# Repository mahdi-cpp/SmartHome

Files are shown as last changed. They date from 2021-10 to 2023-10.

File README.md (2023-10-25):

## Smart Home Automation Project
This Project is designed in 2014 and assembled on more than 200 home in iran

## STM32F103RBT6
The STM32F103xx medium-density performance line family incorporates the high-
performance ARM ® Cortex ® -M3 32-bit RISC core operating at a 72 MHz frequency, high-
speed embedded memories (Flash memory up to 128 Kbytes and SRAM up to 20 Kbytes),
and an extensive range of enhanced I/Os and peripherals connected to two APB buses. All
devices offer two 12-bit ADCs, as well as standard and advanced communication interfaces: up to two I 2 Cs and SPIs, three USARTs, an USB and a CAN.

* PLC (Programmable logic controller) Serial Port Connection
* FAT File System read sound voices 
* Connect To MT8888C Process 
* Connect to VS1003 Via SPI Protocol for Play Voices
* Debugger Serial Port

## ATmega8A-AU
The ATmega8 is a low-power CMOS 8-bit microcontroller based on the AVR RISC architecture.
By executing powerful instructions in a single clock cycle, the ATmega8 achieves throughputs
approaching 1 MIPS per MHz, allowing the system designer to optimize power consumption ver-
sus processing speed.

- Connect to PT2264 remote control encoder and receive commands

## SIM900
SIMCom presents an ultra compact and reliable wireless module-SIM900. This is a complete Quad-band GSM/GPRS module in a SMT type and designed with a very powerful single-chip processor integrating AMR926EJ-S core, allowing you to benefit from small dimensions and cost-effective solutions.

- Send sms notifications to users
- Send sms alarm security to users
- Receive Command of user

## MT8888CS
Integrated DTMF Transceiver with Intel Micro Interface 

- Call users and play alarm security sounds
- Receive user commands

## VS1003
- MP3/WMA AUDIO CODEC: Ring to phone and play mp3 file for user, for example ring and play security sound

## MAX232DR
- Conectin Between STM32F103 <---> PLC
- Conectin Between STM32F103 <---> SIM900
- Conectin Between STM32F103 <---> Debuger

## PT2264
PT2264 is a remote control encoder paired with PT2294 utilizing CMOS Technology. It encodes data
and address pins into a serial coded waveform suitable for RF modulation. PT2264 has a maximum of
12-bit of tri-state address pins providing up to 531,441 (or 312) address codes; thereby, drastically
reducing any code collision and unauthorized code scanning possibilities. 

- 12 Chanel input remote control. for example of usage: lighting control, open door, music ...

<div align="center">
  <a href="https://github.com/othneildrew/Best-README-Template">
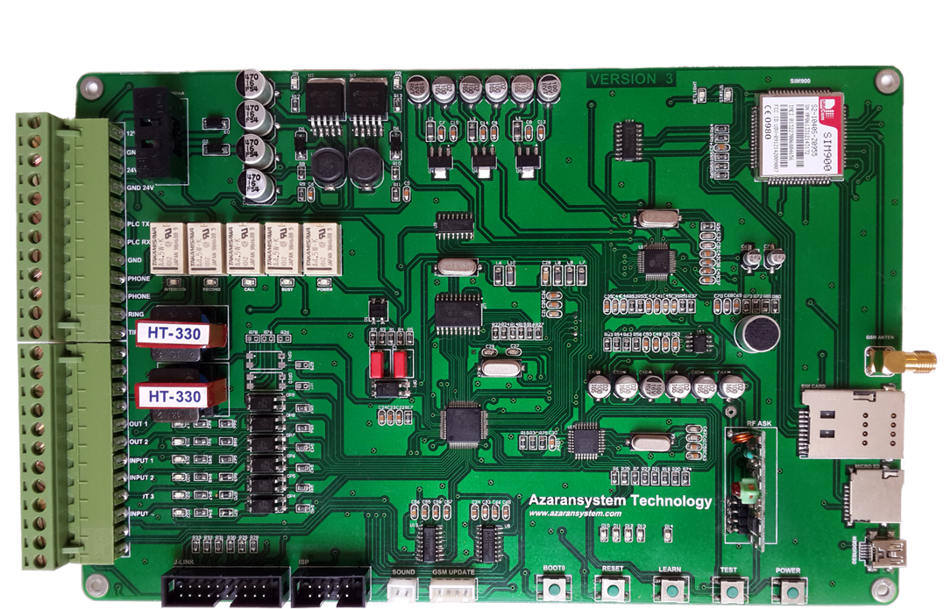
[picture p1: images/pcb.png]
    
  </a>
</div>

<div align="center">
  <a href="https://github.com/othneildrew/Best-README-Template">
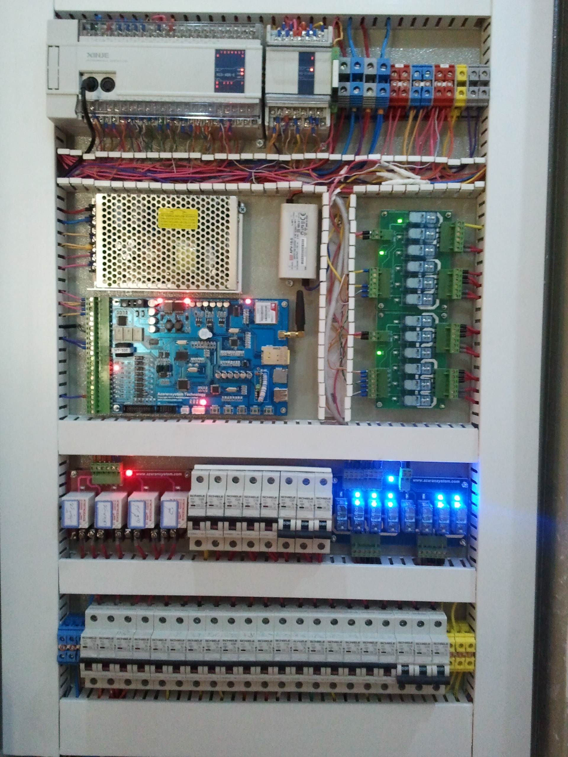
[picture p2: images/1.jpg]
    
  </a>
</div>

<div align="center">
  <a href="https://github.com/othneildrew/Best-README-Template">
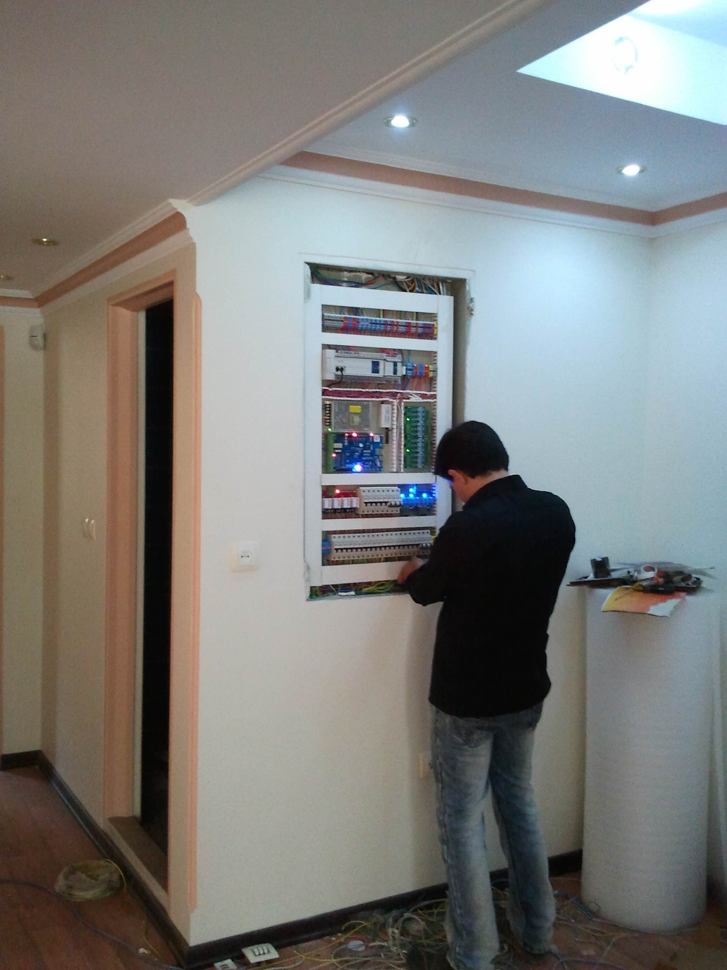
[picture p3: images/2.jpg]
    
  </a>
</div>

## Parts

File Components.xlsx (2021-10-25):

Comment | Designator | Footprint | Quantity
100nF / 100V | C1, C2 | RAD-0.3 | 2
470UF / 16V | C3, C4, C19, C20 | 470UF-SMD | 4
100nF | C5, C6, C7, C8, C9, C13, C14, C15, C22, C23, C24, C25, C26, C30, C33, C34, C35, C37, C38, C40, C41, C42, C43, C49, C50, C51, C52, C54, C55, C56, C57, C58, C59, C63, C65, C66, C69, C70 | 0805C | 38
100uF / 16V SMD | C10, C11, C12, C16, C17, C18, C36, C47, C48, C53, C60, C64 | 100UF-SMD | 12
10nF | C21, C39, C44, C45, C46 | 0805c | 5
15PF | C27, C29, C61, C62, C73, C75, C77 | 0805c | 7
100uF / 100V | C28 | 1206 | 1
33P | C31, C32, C72, C74, C76 | 0805c | 5
10uF | C67, C71 | 10UF-SMD | 2
100pF | C68 | 0805C | 1
ISP | CN1 | IDC2.54-V10D | 1
HD08-T | D1 | HD08-T | 1
Diode 1N4007 | D2, D3 | Diode | 2
LED | D4, D7, D8, D9, D10, D11, D12, D13, D14, D15, D16, D17, D18, D19, D20, D21, D22, D23, NETLIGHT, STATUS | 0805d | 20
1N5822 | D5, D6 | SMB | 2
FUSE 3A | F1 | FUSE | 1
IDC 20 | J-LINK | IDC2.54-V20D | 1
RELAY 5V | K1, K2, K3, K4, K5 | RELAY G6H | 5
FREAT | L1, L2, L3, L6, L7, L8, L9, L10 | 1206 | 8
100UH | L4, L5 | 100UH 1 | 2
sim900 | M1 | sim900 | 1
CON 2PIN | MIC | Microphone | 2
EL817 | OP1, OP4, OP5, OP6, OP7, OP8, OP9, OP10, OP11 | EL817 | 9
FONIX-12 | P1, P2 | Fonit_Conector | 2
Mini USB | P3 | miniusb | 1
RF ASK | P4 | ASK-RF | 1
CON 4 | P5 | CON_4PIN | 1
GSM ANTEN | P6 | anten-jack | 1
CON 2PIN | P7 | CON_2PIN | 1
2.2K | R1 | 0805 | 1
100K | R2, R16, R27, R58 | 0805 | 4
330R | R3, R4 | 0805 | 2
10K | R5, R6, R7, R9, R11, R14, R17, R19, R28, R29, R30, R31, R32, R33, R40, R41, R42, R43, R46, R47, R48, R49, R61, R62, R76 | 0805 | 25
4.7K | R8, R75, R77, R79 | 0805 | 4
3.3K | R10, R24, R35 | 0805 | 3
1K | R12, R13, R18, R20, R21, R22, R25, R34, R38, R39, R44, R45, R53, R56, R57, R64, R65, R66, R67, R68, R69, R70, R71, R72, R73, R74, R80, R81 | 0805 | 28
4.7M | R15 | 0805 | 1
330K | R23 | 0805 | 1
47K | R26 | 0805 | 1
1M | R36 | 0805 | 1
470R | R37 | 0805 | 1
22R | R50, R51, R52, R55, R59, R60 | 0805 | 6
100R | R54, R63 | 0805 | 2
220 | R78 | 0805 | 1
MICRO SD | S1 | MicroSD | 1
SIM CARD SOKET | SIM1 | SIM HOLDER 2 | 1
SWITCH | SW1, SW2, SW3, SW4, SW5 | SWICH | 5
TRANCE 300 :300 | T1, T2 | trance | 2
STM32F103RBT6 | U1 | LQFP64_L | 1
LM2576S-ADJ | U2, U3 | TS5B_N | 2
AMS1117-2.5V | U4 | sot223 | 1
AMS1117-3.3V | U5 | sot223 | 1
AMS1117-2.8V | U6 | sot223 | 1
MT8888CS | U7 | SOIC20_N | 1
MAX232DR | U8, U13 | L16_N | 2
ULN2003L | U9, U14 | L16_N | 2
VS1003 | U10 | 48A | 1
LM386M | U11 | M08A_N | 1
ATmega8A-AU | U15 | 32A_N | 1
3.579545 MHz | X1 | crystal | 1
8MHz | X2 | crystal | 1
12.288MHz | X4 | crystal | 1
16MHz | X5 | crystal | 1

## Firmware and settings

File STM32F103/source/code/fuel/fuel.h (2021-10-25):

#ifndef _FUEL_H
  #define _FUEL_H

  //#include <ctype.h>
  //#include <errno.h>
  //#include <math.h>
  #include <stdio.h>
  #include <stdlib.h>
  #include <string.h>
  #include "ff.h"
  //#include <time.h>
  //#include <wchar.h>
  //#include <wctype.h>



  /* Default configuration filename. */
  #define DEFAULT_CONFIG_FILE "system.txt"
  #define DEFAULT_SD_CONFIG_FILE "1:/machine/machine1/sd.txt"


  #define BUF_SIZ 150
  #define LINE 19
  #define NUM 1
  #define PWD_LEN 6
  #define TRUE 1
  #define FALSE 0
  #define OK  0
  #define ERR  -1
  #define VERSION "1.0.1"

  /*SD卡配置文件action，决定此次配置的动作*/
  enum action
  {
    W_CONFIG = 0,  /*更新配置文件*/
    R_CONFIG,  /*读取配置文件*/
    COPY_TO_SD,  /*拷贝数据到SD卡*/
  };

  /*油箱的形状*/
  enum shape_t
  {
    CYLINDER = 0, CUBE,
  };

  typedef struct cuber_s
  {
    unsigned short height;
    unsigned short length;
    unsigned short width;
  } cube_t;

  typedef struct cylinder_s
  {
    unsigned short len;
    unsigned short radius;
  } cylinder_t;

  union parameter
  {
    cube_t cube;
    cylinder_t cylinder;
  };


  typedef struct config_s
  {
    char name[LINE + 1];
    char pwd[PWD_LEN];
    unsigned short shape;
    unsigned int capacity;
    union parameter u;
  }
  config_t;

  extern config_t g_data;
  extern int load_config(void);
  extern int load_config_from_sd(int *action);
  extern void write_file_tmp(void);

#endif

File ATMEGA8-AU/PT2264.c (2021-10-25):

/*
    This version is compatible PCB Board of VERSION 3 
*/


#include <mega8.h>
#include <stdio.h>
#include <delay.h>

#define      LED_ON            PORTD.7 = 1
#define      LED_OFF           PORTD.7 = 0

#define      BUZZER_ON         PORTC.0 = 1
#define      BUZZER_OFF        PORTC.0 = 0

#define      LEARN             PIND.0

#define      YES               1
#define      NO                0

#define      OK                1

#define      BIT0              0
#define      BIT1              1
#define      FLOATING          2





#define     LED1            PORTD.7
#define     LED2            PORTD.6
#define     LED3            PORTD.5
#define     LED4            PORTD.4

#define     POWER_LED       PORTC.5





#define     RELAY_OUT       PORTB.0 
#define     RELAY_SELECT    PORTB.1
#define     RELAY_POWER     PORTB.2

#define     M8_TO_STM32     PORTC.4


#define     M8_Q0           PORTC.0 
#define     M8_Q1           PORTC.1
#define     M8_Q2           PORTC.2  
#define     M8_Q3           PORTC.3

#define     STM32_Q0        PINC.0 
#define     STM32_Q1        PINC.1 
#define     STM32_Q2        PINC.2 
#define     STM32_Q3        PINC.3 

#define     DELAY           120 

#define     SET_OUTPUT      DDRC = 0x3F 
#define     SET_INPUT       
  
    

short int PowerStatus = 0 , STM32Data, POWER_LED_Cunter, KEY_PRESS = 0;

//char string[20];
int StartPower = 0;

float T1, T2, DutyCycle;

bit RisingEdge = OK, StartT2 = NO, GetPulse = NO, Sync = NO, AddressReceive = NO;

short int i = 0, j = 0, PulseNumber = 1, Pulse1, Pulse2;

short int  AddressData1[12];
short int  AddressData2[12];
short int  AddressData[8];
eeprom short int  EepromAddressData[8];

short int NumberPacket = 1, Error = NO;
//short int receive = 0, 
short int  Data;

void Init(){




PORTB=0x00;
DDRB=0x07;


PORTC=0x00;
DDRC=0x30;


PORTD=0x03;
DDRD=0xF0;



// Timer/Counter 1 initialization
// Clock source: System Clock
// Clock value: 2000.000 kHz
// Mode: Normal top=0xFFFF
// OC1A output: Discon.
// OC1B output: Discon.
// Noise Canceler: Off
// Input Capture on Falling Edge
// Timer1 Overflow Interrupt: Off
// Input Capture Interrupt: Off
// Compare A Match Interrupt: Off
// Compare B Match Interrupt: Off
TCCR1A=0x00;
TCCR1B=0x02;
TCNT1H=0x00;
TCNT1L=0x00;
ICR1H=0x00;
ICR1L=0x00;
OCR1AH=0x00;
OCR1AL=0x00;
OCR1BH=0x00;
OCR1BL=0x00;


  

// External Interrupt(s) initialization
// INT0: On
// INT0 Mode: Rising Edge
// INT1: On
// INT1 Mode: Rising Edge
GICR|=0xC0;
MCUCR=0x0F;
GIFR=0xC0;


    // Global enable interrupts
    #asm("sei")
    

    
    for(i=0; i<8; i++)
       AddressData[i]= EepromAddressData[i];
}



// External Interrupt 0 service routine
interrupt [EXT_INT0] void ext_int0_isr(void)
{
    if(PowerStatus == 1)
    {
        SET_INPUT;
        delay_ms(2);
        STM32Data =  (STM32_Q0 == 1) ? 1 : 0;
		STM32Data += (STM32_Q1 == 1) ? 2 : 0;
		STM32Data += (STM32_Q2 == 1) ? 4 : 0;
		STM32Data += (STM32_Q3 == 1) ? 8 : 0; 
        
        if(STM32Data == 7)
        {
            LED1 = 1;
            LED2 = 1;
            LED3 = 1;
            LED4 = 1; 
            delay_ms(1000);
            LED1 = 0;
            LED2 = 0;
            LED3 = 0;
            LED4 = 0;
        }
    }
        
}

// External Interrupt 1 service routine
interrupt [EXT_INT1] void ext_int1_isr(void)
{
    
    if(RisingEdge == YES)   //Rising Edge
    {  
     
        if(StartT2 == YES)
        {
            T2 = TCNT1;
            StartT2 = NO;
            GetPulse = OK;
        }
        TCNT1 = 0;
        //MCUCR=0x08;     //INT1 Mode : Falling Edge
        RisingEdge = NO; 
        
        // External Interrupt(s) initialization
        // INT0: On
        // INT0 Mode: Rising Edge
        // INT1: On
        // INT1 Mode: Falling Edge
        
        MCUCR=0x0B;
        
    }
    else    // Falling Edge
    {  
        T1 = TCNT1;
        TCNT1 = 0;

        // External Interrupt(s) initialization
        // INT0: On
        // INT0 Mode: Rising Edge
        // INT1: On
        // INT1 Mode: Rising Edge
        
        MCUCR=0x0F;
        
        
        RisingEdge = OK;
        StartT2 = OK;
    }

    if( GetPulse == OK) {
         
        if(Sync == NO)
        {  
            DutyCycle = (T1 / (T1 + T2));
            if(DutyCycle > 0.015 && DutyCycle < 0.035) //Normal 0.0333
            {   
                Sync = OK;
                AddressReceive = YES; 
                Error = NO;
                PulseNumber = 1;
                i = 0;
                j = 0;
            }
        }
        else if(AddressReceive == YES)
        {
            DutyCycle = (T1 / (T1 + T2));

            if(i != 16)
            {
                if(DutyCycle > 0.15 && DutyCycle < 0.3) //4a  Normal 0.239
                {
                    if(PulseNumber == 1)
                        Pulse1 = 4;
                    else if(PulseNumber == 2)
                        Pulse2 = 4; 
                }
                else if(DutyCycle > 0.5 && DutyCycle < 0.8) //12a  Normal 0.729
                {
                    if(PulseNumber == 1)
                        Pulse1 = 12;
                    else if(PulseNumber == 2)
                        Pulse2 = 12; 
                }
                else
                {
                    for(i=0; i<12; i++)
                    {
                        AddressData1[i] = 0;
                        AddressData2[i] = 0;                        
                    }
                        
                    NumberPacket = 1; 
                    Error = NO;   
                    AddressReceive = NO;
                    PulseNumber = 1;
                    Sync = NO;
                    i = 0;
                    j = 0;
                    TCNT1 = 0; 
                    RisingEdge = OK;
                    // External Interrupt(s) initialization
                    // INT0: On
                    // INT0 Mode: Rising Edge
                    // INT1: On
                    // INT1 Mode: Falling Edge
                    
                    MCUCR=0x0B;
                  
                    
                    StartT2 = NO;
                    GetPulse = NO;
                    goto EndInterrupt;
                }

                if(PulseNumber == 2)
                {
                    if( Pulse1 == 4 && Pulse2 == 4)
                    {
                        if(NumberPacket == 1)
                            AddressData1[j] = BIT0 ; 
                        else if(NumberPacket == 2)
                            AddressData2[j] = BIT0 ;
                    }    
                    else if(Pulse1 == 12 && Pulse2 == 4)
                    {
                        if(NumberPacket == 1)
                            AddressData1[j] = BIT1 ; 
                        else if(NumberPacket == 2)
                            AddressData2[j] = BIT1 ;
                    }                        
                    else if(Pulse1 == 4 && Pulse2 == 12)
                    {  
                        if(NumberPacket == 1)
                            AddressData1[j] = FLOATING ; 
                        else if(NumberPacket == 2)
                            AddressData2[j] = FLOATING ;
                    }
                    j++;
                }
                                                               
                
                if(PulseNumber == 1) 
                    PulseNumber = 2;
                else if(PulseNumber == 2)
                    PulseNumber = 1;
            }

            i++;
            
            if(i > 23)
            {
                
                if(NumberPacket == 2)
                {   
                    for(i=0; i<12; i++)
                        if(AddressData1[i] != AddressData2[i])
                            Error = YES;
                    
                    if(Error == NO)
                    {   
                        if(!LEARN)
                        {
                            for(i=0; i<4; i++)
                            {   
                                LED1 = 1;
                                LED2 = 1;
                                LED3 = 1;
                                LED4 = 1;
                                delay_ms(100);
                                LED1 = 0;
                                LED2 = 0;
                                LED3 = 0;
                                LED4 = 0;  
                                delay_ms(100);
                                //BUZZER_ON;
                                //delay_ms(50);
                                //BUZZER_OFF;
                                //delay_ms(50);  
                            }
                            
                            for(i=0; i<8; i++)
                            {
                                EepromAddressData[i] = AddressData1[i]; 
                                AddressData[i] = AddressData2[i]; 
                                //lcd_clear();
                                //sprintf(string, "%0d %0d %0d %0d %0d %0d %0d %0d", AddressData[0] , AddressData[1], AddressData[2], AddressData[3], AddressData[4], AddressData[5], AddressData[6], AddressData[7]);
                                //lcd_gotoxy(0, 0);
                                //lcd_puts(string);
                            }    
                        }
                        else
                        {  
                            Error = NO;
                            
                            for(i=0; i<8; i++)
                            {
                                if(AddressData[i] != AddressData2[i])
                                {
                                    Error = YES;  
                                    
                                    //lcd_clear();   
                                    //sprintf(string, "%0d %0d %0d %0d %0d %0d %0d %0d", AddressData2[0] , AddressData2[1], AddressData2[2], AddressData2[3], AddressData2[4], AddressData2[5], AddressData2[6], AddressData2[7]);
                                    //lcd_gotoxy(0, 0);
                                    //lcd_puts(string);
                                    //sprintf(string, "NO MATCH ADDRESS");
                                    //lcd_gotoxy(0, 1);
                                    //lcd_puts(string);  

                                    LED1 = 1;
                                    LED2 = 1;
                                    LED3 = 1;
                                    LED4 = 1;
                                    delay_ms(200);
                                    LED1 = 0;
                                    LED2 = 0;
                                    LED3 = 0;
                                    LED4 = 0;

                                } 
                            }
                                    
                            if(Error == NO)
                            {
                                
                                //lcd_clear();
                                //sprintf(string, "%0d %0d %0d %0d %0d %0d %0d %0d", AddressData1[0] , AddressData1[1], AddressData1[2], AddressData1[3], AddressData1[4], AddressData1[5], AddressData1[6], AddressData1[7]);
                                //lcd_gotoxy(0, 0);
                                //lcd_puts(string);

                                Data = ((AddressData1[8]*1000) + (AddressData1[9]*100) + (AddressData1[10]*10) + AddressData1[11]);
                                LED1 = 0;
                                LED2 = 0;
                                LED3 = 0;
                                LED4 = 0;
                                switch(Data){
                                    case 20:      //0001 
                                        Data = 1;
                                        LED4 = 1; 
                                        break; 
                                    case 210:     //0010   
                                        Data = 2;
                                        LED3 = 1; 
                                        break;
                                    case 200:     //0011 
                                        Data = 3;
                                        LED3 = 1;  
                                        LED4 = 1;
                                        break; 
                                    case 2100:    //0100 
                                        Data = 4;
                                        LED2 = 1;  
                                        break; 
                                    case 2120:    //0101    
                                        LED2 = 1;
                                        LED4 = 1;
                                        Data = 5;
                                        break;
                                    case 2010:    //0110 
                                        LED2 = 1;
                                        LED3 = 1;
                                        Data = 6;
                                        break;
                                    case 2000:   //0111  
                                        LED2 = 1;
                                        LED3 = 1;
                                        LED4 = 1;
                                        Data = 7;
                                        break; 
                                    case 1000:   //1000
                                        LED1 = 1;
                                        Data = 8;
                                        break;
                                    case 1020:   //1001
                                        LED1 = 1;
                                        LED4 = 1;
                                        Data = 9;
                                        break; 
                                    case 1210:   //1010  
                                        LED1 = 1;
                                        LED3 = 1;
                                        Data = 10; 
                                        break; 
                                    case 1200: //1011
                                        LED1 = 1;
                                        LED3 = 1;
                                        LED4 = 1;
                                        Data = 11;
                                        break;
                                    case 100: // 1100
                                        LED1 = 1;
                                        LED2 = 1;
                                        Data = 12;
                                        break;
                                }
                                
                                SET_OUTPUT;
                                M8_Q0 = LED4; 
                                M8_Q1 = LED3;
                                M8_Q2 = LED2;
                                M8_Q3 = LED1; 
                                
                                delay_ms(2);
                                
                                M8_TO_STM32 = 1;
                                delay_ms(8);
                                M8_TO_STM32 = 0; 
                                delay_ms(8);
                                M8_Q0 = 0;
                                M8_Q1 = 0;
                                M8_Q2 = 0;
                                M8_Q3 = 0;
                                SET_INPUT;
                                
                                //sprintf(string, "%0d", Data);
                                //lcd_gotoxy(0, 1);
                                //lcd_puts(string);
                                //receive = 1; 
                            }
                        }
                        
                    }  
                    for(i=0; i<12; i++)
                    {
                        AddressData1[i] = 0; 
                        AddressData2[i] = 0;
                    }
                    NumberPacket = 1;     
                } 
                else
                { 
                    NumberPacket = 2;
                }
                
                Error = NO;
                AddressReceive = NO;
                PulseNumber = 1;
                Sync = NO;
                i = 0;
                j = 0;
                TCNT1 = 0;
                RisingEdge = OK;

                // External Interrupt(s) initialization
                // INT0: On
                // INT0 Mode: Rising Edge
                // INT1: On
                // INT1 Mode: Falling Edge
               
                MCUCR=0x0B;
                
                    
                RisingEdge = OK;
                StartT2 = NO;
                GetPulse = NO;
                goto EndInterrupt;
            }
        }

        GetPulse = NO;
    }
    EndInterrupt: 
 
    //Add to version 2     
    POWER_LED_Cunter++;
    if(POWER_LED_Cunter > 5000 && PowerStatus == 1)
    {
        POWER_LED = 1 ;
    }
    if(POWER_LED_Cunter > 5500 && PowerStatus == 1)
    {
        POWER_LED = 0 ;
        POWER_LED_Cunter = 0; 
    } 
}
//-----------------------------------------------------------------------------------



void main(void)
{
    POWER_LED = 0;
    Init();

      while (1)
      {
           /* 
            if(!LEARN){
                M8_TO_STM32 = 1;
                delay_ms(250);
                M8_TO_STM32 = 0;
            }
           */
            if(StartPower == 0)
            {   
                POWER_LED = 0;
                delay_ms(4000); 
                LED1 = 1;
                delay_ms(DELAY);                
                LED1 = 0; 
                LED2 = 1;
                delay_ms(DELAY);                 
                LED2 = 0; 
                LED3 = 1;
                delay_ms(DELAY);                  
                LED3 = 0; 
                LED4 = 1;
                delay_ms(DELAY);   
                LED4 = 0; 
                
                
                //RELAY_OUT = 1;
                RELAY_POWER = 1;
                
                PowerStatus = 1;
                delay_ms(20);
                
                StartPower = 1;
            }
             
            
            if(PIND.1 == 1) 
                KEY_PRESS = 0;
                
            if(PIND.1 == 0 && PowerStatus == 0 && KEY_PRESS == 0)
            {  
                KEY_PRESS = 1;
                
                LED1 = 1;
                delay_ms(DELAY);                
                LED1 = 0; 
                LED2 = 1;
                delay_ms(DELAY);                 
                LED2 = 0; 
                LED3 = 1;
                delay_ms(DELAY);                  
                LED3 = 0; 
                LED4 = 1;
                delay_ms(DELAY);   
                LED4 = 0; 
                POWER_LED = 0;
                
                //RELAY_OUT = 1;
                RELAY_POWER = 1;
                
                PowerStatus = 1;
                delay_ms(20);
            }
            else if(PIND.1 == 0 && PowerStatus == 1 && KEY_PRESS == 0) //if Device On
            {    
                KEY_PRESS = 1;
                
                PowerStatus = 0;
                POWER_LED = 0;    
                LED4 = 1;
                delay_ms(DELAY);                
                LED4 = 0; 
                LED3 = 1;
                delay_ms(DELAY);                 
                LED3 = 0; 
                LED2 = 1;
                delay_ms(DELAY);                  
                LED2 = 0; 
                LED1 = 1;
                delay_ms(DELAY);   
                LED1 = 0; 
                
                //RELAY_OUT = 0;
                RELAY_POWER = 0; 
                                
                delay_ms(20);
            } 
            
            
 }                 
}

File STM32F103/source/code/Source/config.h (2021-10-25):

#ifndef __Config_h
#define __Config_h

//#include "stm32f10x.h"
#include "stm32f10x_lib.h"
#include "stm32f10x_type.h"
#include "integer.h"
#include "delay.h"
#include <stdio.h>
#include <string.h>
#include <stdlib.h>
#include <math.h>
#include "ff.h"
#include "RTC_Time.h"
#include "stm32f10x_rcc.h"
#include "fuel.h"
#include "Serial.h"
#include "SerialProcess.h"
#include "shell.h"
#include "FATFS_cmds.h"
#include "stm32f10x_exti.h"


#define BITBAND(addr, bitnum) ((addr & 0xF0000000)+0x2000000+((addr &0xFFFFF)<<5)+(bitnum<<2)) 
#define MEM_ADDR(addr)  *((volatile unsigned long  *)(addr)) 
#define BIT_ADDR(addr, bitnum)   MEM_ADDR(BITBAND(addr, bitnum)) 

#define GPIOA_ODR_Addr    (GPIOA_BASE+12) //0x4001080C 
#define GPIOB_ODR_Addr    (GPIOB_BASE+12) //0x40010C0C 
#define GPIOC_ODR_Addr    (GPIOC_BASE+12) //0x4001100C 
#define GPIOD_ODR_Addr    (GPIOD_BASE+12) //0x4001140C 
#define GPIOE_ODR_Addr    (GPIOE_BASE+12) //0x4001180C 
#define GPIOF_ODR_Addr    (GPIOF_BASE+12) //0x40011A0C    
#define GPIOG_ODR_Addr    (GPIOG_BASE+12) //0x40011E0C    

#define GPIOA_IDR_Addr    (GPIOA_BASE+8) //0x40010808 
#define GPIOB_IDR_Addr    (GPIOB_BASE+8) //0x40010C08 
#define GPIOC_IDR_Addr    (GPIOC_BASE+8) //0x40011008 
#define GPIOD_IDR_Addr    (GPIOD_BASE+8) //0x40011408 
#define GPIOE_IDR_Addr    (GPIOE_BASE+8) //0x40011808 
#define GPIOF_IDR_Addr    (GPIOF_BASE+8) //0x40011A08 
#define GPIOG_IDR_Addr    (GPIOG_BASE+8) //0x40011E08 
 

#define PAout(n)   BIT_ADDR(GPIOA_ODR_Addr,n) 
#define PAin(n)    BIT_ADDR(GPIOA_IDR_Addr,n) 

#define PBout(n)   BIT_ADDR(GPIOB_ODR_Addr,n)  
#define PBin(n)    BIT_ADDR(GPIOB_IDR_Addr,n) 

#define PCout(n)   BIT_ADDR(GPIOC_ODR_Addr,n) 
#define PCin(n)    BIT_ADDR(GPIOC_IDR_Addr,n)  

#define PDout(n)   BIT_ADDR(GPIOD_ODR_Addr,n)  
#define PDin(n)    BIT_ADDR(GPIOD_IDR_Addr,n) 

#define PEout(n)   BIT_ADDR(GPIOE_ODR_Addr,n)  
#define PEin(n)    BIT_ADDR(GPIOE_IDR_Addr,n)  

#define PFout(n)   BIT_ADDR(GPIOF_ODR_Addr,n)  
#define PFin(n)    BIT_ADDR(GPIOF_IDR_Addr,n)  

#define PGout(n)   BIT_ADDR(GPIOG_ODR_Addr,n)  
#define PGin(n)    BIT_ADDR(GPIOG_IDR_Addr,n)  

#define 	KeyTest   		 PCin(15)

#define 	ON         			1
#define 	OFF        			0

#define 	VALID         		 1
#define 	INVALID        		-1

#define		ENTER				-8
#define		EXIT				-9



#define 	RELAY_RECORD   		PAout(8)
#define 	RELAY_INTERCOM   		PCout(14)
#define 	RELAY_BUSY   			PCout(15)
#define 	RELAY_CALL   			PDout(2)



extern int RemotDelay;
extern int PrintfSelect;
extern int PLC_Telephone_Request ;

extern u8 TimeDisplay;
extern FATFS fs[2]; // Work area (file system object) for logical drive
extern FIL fsrc, fdst, fap, file, fii; // file objects
extern FRESULT res, re; // FatFs function common result code
extern UINT br, bw, bt;
 // File R/W count
extern FILINFO finfo, fno;
extern DIR dirs;
extern time_t current_time;
extern struct tm time_now;
extern u8 passwordflag;
extern u16 AD_value_mul4;
extern char machine[20];
extern u8 timeFirstSet;
extern char shellEnable;
#define UPDATESECONDS 3

extern u16 filter(void);

#endif

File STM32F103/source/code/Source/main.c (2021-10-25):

#include "config.h"
#include "string.h"
#include "stm32f10x_lib.h"
#include "init.h"
#include "VS1003.h"
#include "MT8888C.h"
#include "SIM900.h"
#include "PLC.h"
#include "ATMEGA8.h"

#include "PhoneService.h"

//-------------------------------------------------------------
char IR_Remote_Data[12];


//-------------------------------------------------------------

FATFS fs[2]; // Work area (file system object) for logical drive
FIL fsrc, fdst, fap; // file objects
FRESULT res, re; // FatFs function common result code
UINT br, bw, bt;


#define FILEAMOUNT 11


char machine[20] = "machine1";
char shellEnable = FALSE;


long int SystemStart = -1;

int PrintfSelect = 3;

int RemotDelay;

static int tmp[3], index=0;

int PLC_Telephone_Request = 0;

void TIM_Configuration(void);

   uchar Alert_Sound12[20];

int main(void) {

	char str[] = "Hello mhdi12 123456789";
    char key[] = "mehdi";
	char *pch;

	RCC_Configuration();
	NVIC_Configuration();
	USART3_Configuration();

	Delay_init(72); 

	SPI_Configuration();
 	VS1003B_Init();

	printf("\rVS1003 Init...");

   VS1003B_WriteCMD(0x0b, 0x0a, 0x0a);

   f_mount(1, &fs[1]);	

	delay_ms(50);
	SIM900_Init();



	delay_ms(50);
	PLC_Init();
	ATMEGA8_Init();

  delay_ms(50);
	MT8888C_Init();
	MT8888C_DTMF_Receive_Init();



	
	
	TIM_Configuration();
	if(SIM900_TurnOn() == 2){
		SIM900_TurnOn_Config = 1;
	}

	PrintfSelect = 1;
	printf("123456");
	delay_ms(900);

	GetPassword();


//	delay_ms(900);
//	delay_ms(900);


  
	//Call_Alert(A_PhoneNumber, 1);
	//Call_Alert(B_PhoneNumber, 1);
	//Call_Alert(C_PhoneNumber, 1);
	
	//ServiceRecord();
	
	//play_file("1:/system/welcome.mp3"); 	//Welcome to System

   /*
   	sprintf(Alert_Sound12, "1:/Alert/%c.mp3" , 52);

	PrintfSelect = 3;
	printf("\rPlay File: %s", Alert_Sound12);

	PhoneServicePlay(Alert_Sound12);
	*/

	
	printf("\rSystem Start...");
	//PhoneServicePlay("1:/system/welcome.mp3"); 	//Welcome to System
	//RELAY_BUSY = ON;
	
   //PrintfSelect = 2;
	//printf("AT+CSQ");
	//printf("\r");

	
	//PrintfSelect = 2;
	//printf("AT+CMGF=1\r");
		

	
	//PhoneServicePlay("1:/system/welcome.mp3"); 	//Welcome to System
	
	while(1)
	{
		//PrintfSelect = 1;
    	//printf("PPP");
		//PLC_Telephone_Password = 3;

		//GetPassword();
		//PhoneService();
		//PrintfSelect = 1;


	 	if(RingCounter >= 8)
	 	{
			PhoneService();
	 	}
		
 
	 	//PLC_OUT_1 = !PLC_OUT_1;	

		delay_ms(50);

	}
}








/*******************************************************************************
 * Function Name  : TIM2_IRQHandler
 * Description    : This function handles TIM2 global interrupt request.
 * Input          : None
 * Output         : None
 * Return         : None
 *******************************************************************************/

void TIM2_IRQHandler(void) //10ms
{
	static int count = 0, Interupt_13_Counter , RingTone_Counter = 0 ,  RingTemp = 0;;
	
	if (TIM_GetITStatus(TIM2, TIM_IT_Update) != RESET) 
   {
		TIM_ClearITPendingBit(TIM2, TIM_IT_Update);       
 	 
		RemotDelay++;
		RingTone_Counter++;

	  //--------------------------------System Service-----------------------------------
	  count++;
	  if(count == 50)
	  {	
			PLC_OUT_2 =! PLC_OUT_2;	
			count = 0;		
	  }
	  //--------------------------------Phone Service-----------------------------------
	  PhoneServiceTimeout++;
	  
	  if(PhoneServiceTimeout > 50000)
	  {
			PhoneServiceTimeout = 0;// Reset value		
	  }
			
	  //--------------------------------SIM900 Service-----------------------------------
	  
	  	SIM900_Power_Tiomout++;
		SystemStart++;
		 
		if(SIM900_TurnOn_Config > 0) // if SIM900 is Turn off  during sytem start.
			 SIM900_TurnOn_Config++;
		
	  if(SIM900_Timer_1 == 1)
		{

			PrintfSelect = 2;
			printf("AT+CMGL=\"ALL\"");
			delay_ms(20);
			printf("\r");
			
			//delay_ms(50);
			
			//PrintfSelect = 2;
			//printf("AT+CMGL=\"ALL\"");
			//delay_ms(20);
			//printf("\r");
			
			SIM900_Timer_1 = 0;
						
			//PrintfSelect = 3;
			//printf("\rSIM900_Timer_1...");
			
		}
		
		if((SIM900_Timer_2 == 1) || (SystemStart == -1) || (SystemStart >4320000)) //Clear Value next 12 hour
		{	
			SIM900_Connfig = 1;
			
			SIM900_ClearSMS();
			delay_ms(50);
			SIM900_ClearSMS();
			delay_ms(50);
			
			SIM900_Read_SMS();
			delay_ms(50);
			SIM900_Read_SMS();

			
			SIM900_Timer_2 = 0;
			SystemStart = 1;
			
			delay_ms(50);
			SIM900_Connfig = 0;
			
			//PrintfSelect = 3;
			//printf("\rSIM900_Timer_2...");
		}
		
		if((SIM900_TurnOn_Config >= 1200)) //Clear Value next 8 minute
		{
			PrintfSelect = 2;
			printf("AT");
			printf("\r");
			delay_ms(20);
			
			SIM900_ClearSMS();
			delay_ms(50);
			SIM900_ClearSMS();
			
			SIM900_Read_SMS();
			delay_ms(50);
			SIM900_Read_SMS();
			
			
			SIM900_Timer_2 = 0;
			SystemStart = 1;			
			SIM900_TurnOn_Config = 0;
			
			PrintfSelect = 3;
			printf("\rSIM900_TurnOn_Config...");
		}
		
		
		//---------------------------------------------------------------------------------		
		if(Start_Telephone == 1)
		{
			Interupt_13_Counter++;			
		}
		
		if(Interupt_13_Counter > 50)
		{
			Interupt_13_Counter = 0;
			if(StartTelephoneSelect == 1)
			{
				RELAY_BUSY = 1;
				Start_Telephone = 1;
			}
			else
			{
				RELAY_BUSY = 0;
				Start_Telephone = 0;
				StartTelephoneSelect = 0;
			}			
		}
		
		//---------------------------------------------------------------------------------		
		if(RingTone_Counter > 600)// This section used for  zero ringCounter if not Detect Ring
		{
			 if(RingCounter == 1){
				  RingTemp = 1;
			 }
			 else if(RingCounter > RingTemp){
				 RingTemp = RingCounter;
			 }
			 else{
				  RingCounter = 0;
					RingTemp = 0;
			 }

			 //PrintfSelect = 3;
			 //printf("\rRingTone_Counter ..........");
			
			 RingTone_Counter = 0;
		}
		//---------------------------------------------------------------------------------		
		
	}
}
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

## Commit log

2021-10-25 Add STM32F103 Source Code
2021-10-25 Add Components
    [Components.xlsx]
